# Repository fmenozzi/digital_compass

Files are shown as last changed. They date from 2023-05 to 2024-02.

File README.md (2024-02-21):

A digital compass that uses an LED ring to display the compass rose.

Upon startup, the compass enters magnetometer calibration mode, shown by the led chase sequence:

https://github.com/fmenozzi/digital_compass/assets/4451432/49a2e2fe-652e-430a-9320-a2c4e0b69866

During calibration, the compass should be moved around in all directions. Calibration ends after calibrated values do not change for five seconds.

Once the chase sequence ends, the compass rose will be displayed and the compass is now active, with the red LED pointing *very roughly* north:

https://github.com/fmenozzi/digital_compass/assets/4451432/9e37ce8d-d3a7-4e10-ac38-1c5cc8147863

Accuracy will suffer for a couple of reasons, such as being limited to only 24 possible directions and the magnetometer calibration being suboptimal. Regardless, this was a fun little proof-of-concept project for me, and my first non-trivial hardware project.

The microcontroller is a Seeeduino Xiao, and the magnetometer board uses the QMC5883L chip. The LED ring is an Adafruit Neopixel Ring 24, and a basic level shifter board does the conversions between the Xiao's needed 3.3V and 5V.

The software was programmed using Arduino. The circuit board was designed in KiCAD and manufactured by JLCPCB. The 3D-printed enclosure was designed in FreeCAD.

All software, schematics, and design files are licensed under the [MIT license](https://mit-license.org/).

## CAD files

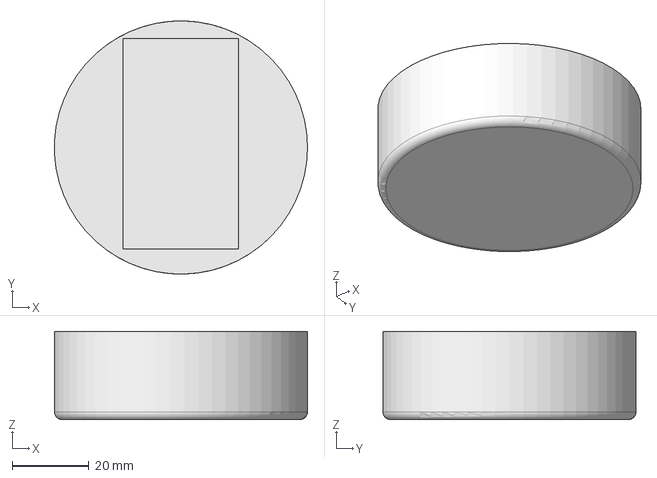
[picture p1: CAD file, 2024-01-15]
enclosure/bottom.FCStd
65.9 x 66.0 x 23.0 mm

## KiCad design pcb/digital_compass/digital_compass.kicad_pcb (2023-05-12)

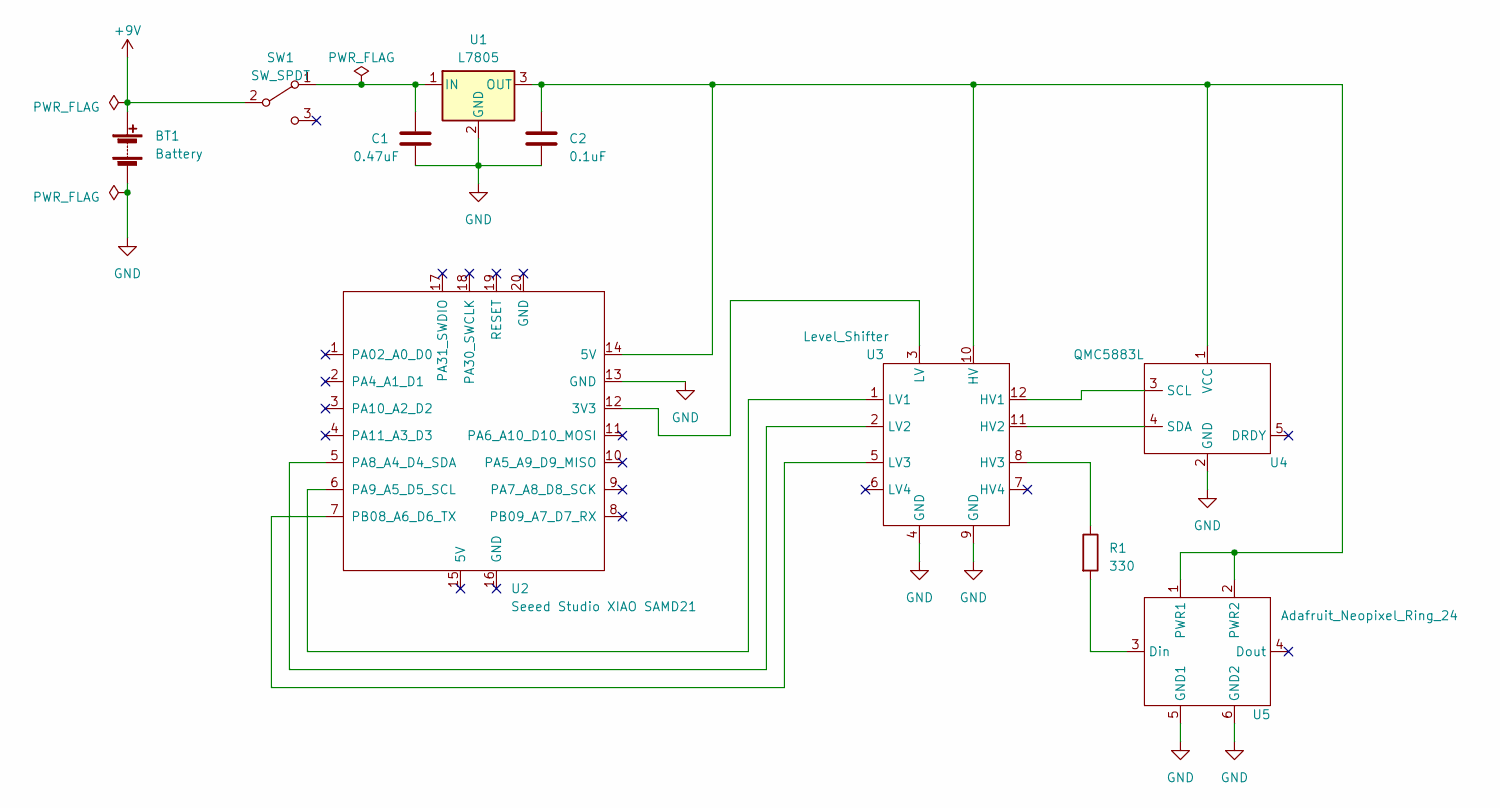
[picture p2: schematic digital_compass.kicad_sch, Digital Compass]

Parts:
BT1: Battery; BatteryHolder_Eagle_12BH611-GR
C1: 0.47uF; C_1206_3216Metric_Pad1.33x1.80mm_HandSolder
C2: 0.1uF; C_1206_3216Metric_Pad1.33x1.80mm_HandSolder
R1: 330; R_1206_3216Metric_Pad1.30x1.75mm_HandSolder
SW1: SW_SPDT; JS102011SCQN_SPDT_Switch
U1: L7805; TO-252-3_TabPin2
U2: Seeed Studio XIAO SAMD21; XIAO-SAMD21-RP2040-14P-2.54-21X17.8MM (Seeeduino XIAO)
U3: Level_Shifter
U4: QMC5883L
U5: Adafruit_Neopixel_Ring_24; Adafruit Neopixel Ring 24

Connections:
+9V: BT1.1 (+), SW1.2 (B)
GND: BT1.2 (-), C1.2, C2.2, U1.2 (GND), U2.13 (GND), U3.4 (GND), U3.9 (GND), U4.2 (GND), U5.5 (GND1), U5.6 (GND2)
unnamed: C1.1, SW1.1 (A), U1.1 (IN)
unnamed: C2.1, U1.3 (OUT), U2.14 (5V), U3.10 (HV), U4.1 (VCC), U5.1 (PWR1), U5.2 (PWR2)
unnamed: U2.12 (3V3), U3.3 (LV)
unnamed: U2.5 (PA8_A4_D4_SDA), U3.2 (LV2)
unnamed: U2.6 (PA9_A5_D5_SCL), U3.1 (LV1)
unnamed: U2.7 (PB08_A6_D6_TX), U3.5 (LV3)
unnamed: U3.12 (HV1), U4.3 (SCL)
unnamed: U3.11 (HV2), U4.4 (SDA)
unnamed: R1.1, U3.8 (HV3)
unnamed: R1.2, U5.3 (Din)

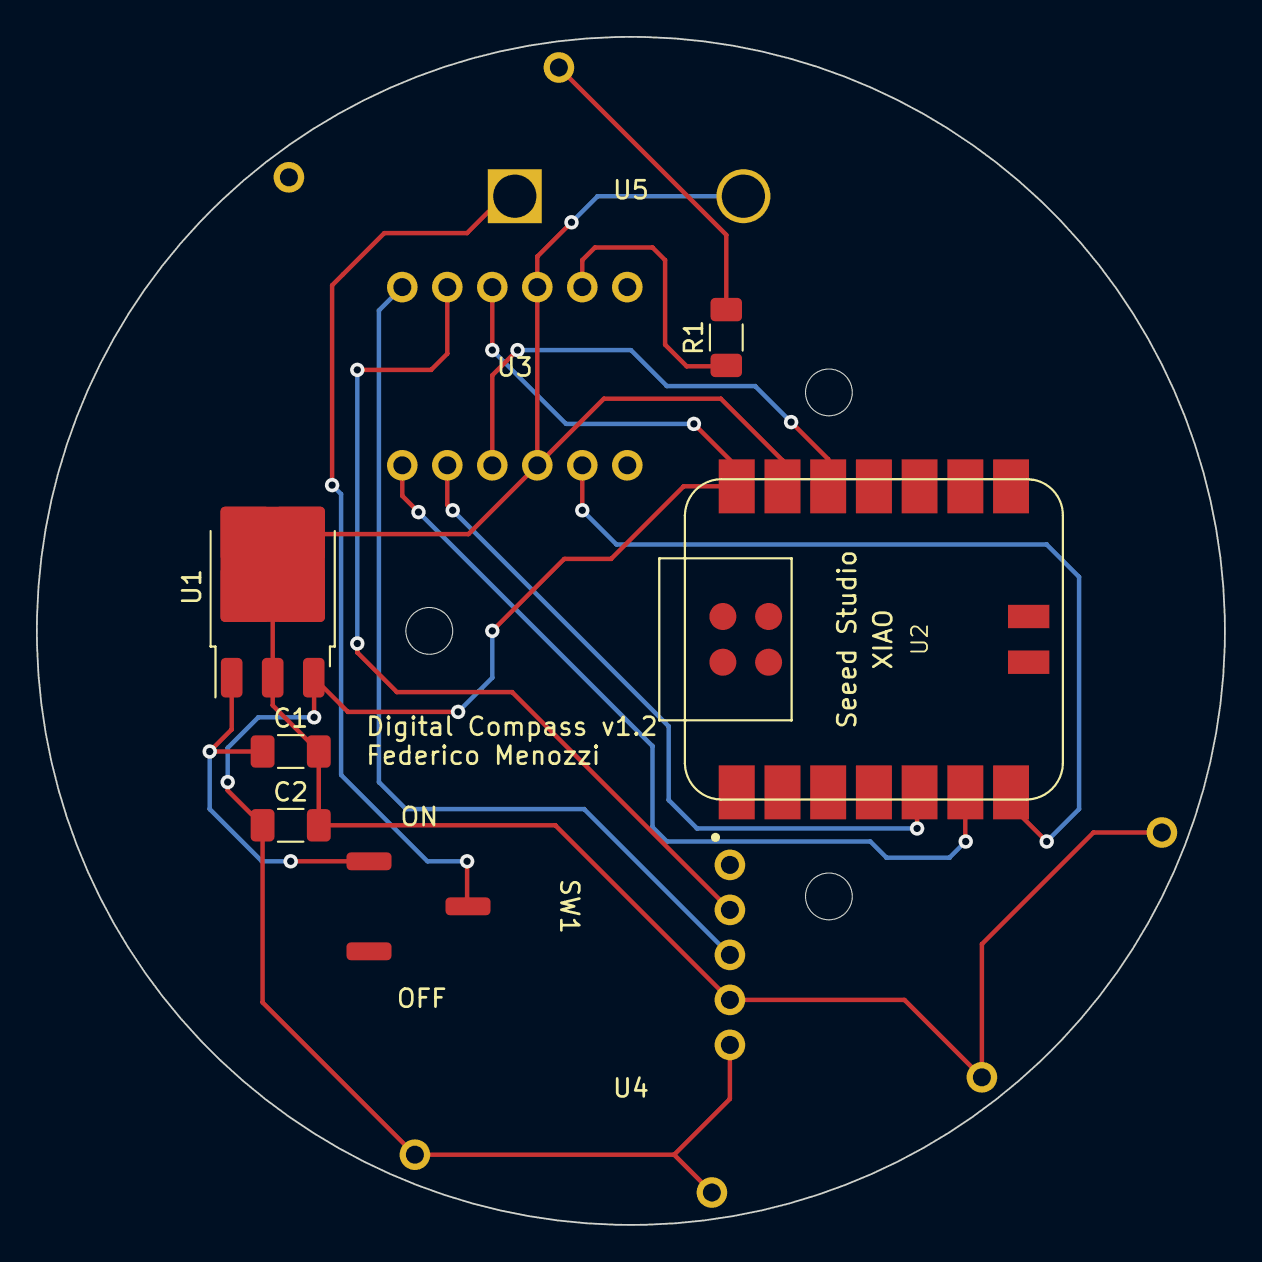
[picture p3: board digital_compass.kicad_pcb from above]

Board: 2 copper layers, 66.0 x 66.0 mm, 10 parts (1 on the bottom side), 12 nets.

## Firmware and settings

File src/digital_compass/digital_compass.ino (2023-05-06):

#include <FastLED.h>
#include <QMC5883LCompass.h>

const int NUM_LEDS = 24;
const int DATA_PIN = 6;
const int DELAY_MS = 50;

CRGB ring[NUM_LEDS];

QMC5883LCompass compass;

void setup() {
  FastLED.addLeds<NEOPIXEL, DATA_PIN>(ring, NUM_LEDS);
  FastLED.setBrightness(32);
  FastLED.clear();

  calibrate();
}

void calibrate() {
  int x0 = 0, x1 = 0, y0 = 0, y1 = 0, z0 = 0, z1 = 0;
  int i0 = 0, i1 = 1, i2 = 2, i3 = 3;
  int x, y, z;
  bool changed = false;
  int t = 0;
  int c = 0;

  compass.init();

  while (1) {
    // Nice ring chase sequence while we calibrate.
    FastLED.clear();
    ring[i0] = CRGB::White;
    ring[i1] = CRGB::White;
    ring[i2] = CRGB::White;
    ring[i3] = CRGB::Red;
    FastLED.show();
    i0 = (i0 + 1) % NUM_LEDS;
    i1 = (i1 + 1) % NUM_LEDS;
    i2 = (i2 + 1) % NUM_LEDS;
    i3 = (i3 + 1) % NUM_LEDS;
    delay(40);

    compass.read();
    x = compass.getX();
    y = compass.getY();
    z = compass.getZ();

    changed = false;
    if (x < x0) {
      x0 = x;
      changed = true;
    }
    if (x > x1) {
      x1 = x;
      changed = true;
    }
    if (y < y0) {
      y0 = y;
      changed = true;
    }
    if (y > y1) {
      y1 = y;
      changed = true;
    }
    if (z < z0) {
      z0 = z;
      changed = true;
    }
    if (z > z1) {
      z1 = z;
      changed = true;
    }

    if (changed) {
      c = millis();
    }

    t = millis();

    if (t - c > 5000) {
      FastLED.clear();
      break;
    }
  }

  compass.setCalibration(x0, x1, y0, y1, z0, z1);
}

void draw_compass(int north_led_idx) {
  int idx_n = north_led_idx;
  int idx_e = (idx_n + NUM_LEDS*1/4) % NUM_LEDS;
  int idx_s = (idx_n + NUM_LEDS*2/4) % NUM_LEDS;
  int idx_w = (idx_n + NUM_LEDS*3/4) % NUM_LEDS;

  ring[idx_n] = CRGB::Red;
  ring[idx_e] = CRGB::White;
  ring[idx_s] = CRGB::White;
  ring[idx_w] = CRGB::White;

  FastLED.show();

  ring[idx_n] = CRGB::Black;
  ring[idx_e] = CRGB::Black;
  ring[idx_s] = CRGB::Black;
  ring[idx_w] = CRGB::Black;
}

// Determine the index of the Neopixel ring that corresponds to north, given
// the magnetometer heading in degrees. The top LED (that is, the LED pointing
// in the X-direction of the magnetometer) is index 0.
//
// Note that we want each arc centered on the LED, and not the LED's edge (e.g.
// for a Neopixel Ring 24, the arc angle will be 15 degrees, but since it's
// centered on the LED, the top LED will shine when the heading is between 352.5
// and 7.5 degrees).
//
// TODO: See if there's a closed form representation for this that doesn't
//       require this loop.
int convert_heading_to_north_led_index(float heading_deg) {
  const float ARC_ANGLE = 360.0 / NUM_LEDS;
  const float HALF_ARC_ANGLE = ARC_ANGLE / 2.0;
  for (int i = 0; i < NUM_LEDS; i++) {
    if (heading_deg < i*ARC_ANGLE + HALF_ARC_ANGLE) {
      return (NUM_LEDS - i) % NUM_LEDS;
    }
  }
  return NUM_LEDS - 1; // For the last half-arc
}

void loop() {
  compass.read();
  float heading = compass.getAzimuth();

  int north_led_idx = convert_heading_to_north_led_index(heading);
  draw_compass(north_led_idx);

  delay(DELAY_MS);
}

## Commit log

2022-12-10 Add preliminary code implementation.
    This code provides the bare-minimum functionality of a digital compass;
    that is, it measures the heading from the qmc5883l magnetometer and
    lights the appropriate leds on a 24-piece neopixel ring (i.e. in the
    cardinal directions).
    Future additions might include a debug mode for displaying magnetometer
    readings via serial, adding a calibration mode instead of hardcoding a
    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
2022-12-10 Create empty kicad project.
    [digital_compass.kicad_pcb, digital_compass.kicad_sch]
2022-12-11 Add initial footprint for neopixel ring 24.
    Not sure yet whether the hollow ring aspect was captured properly here.
2022-12-11 Add symbol for QMC5883L magnetometer.
2022-12-11 Add footprint for QMC588L.
2023-04-22 Finish basic digital compass schematic.
    * Based on updated xiao-based design
    * Also opened in KiCad 7
    [digital_compass.kicad_pcb, digital_compass.kicad_sch]
2023-04-23 Add/update footprints and run fp assignment.
    The footprints for the level shifter and magnetometer boards were
    created manually, but the xiao symbol/footprint were taken from
    https://github.com/Seeed-Studio/OPL_Kicad_Library.
    Note that the xiao symbol was lightly tweaked to pass ERC, as the pins
    were not properly labeled as power inputs/outputs, bidirectional, etc.
    [digital_compass.kicad_sch]
2023-04-23 Add SPDT slide power switch.
    For now we just choose an ok-looking smd footprint but we may need to
    make a custom one depending on what we actually find with suppliers.
    [digital_compass.kicad_sch]
2023-04-23 Use custom footprint for SPDT switch.
    Based on https://www.ckswitches.com/media/1422/js.pdf. Also move the
    switch to the regulated side of the L7805, as this switch can only
    handle up to 6V.
    [digital_compass.kicad_sch]
2023-04-23 Create initial layout (no traces).
    The magnetometer and level shifter boards may be changed to use
    throughhole footprints instead of smd, but the size/layout shouldn't
    need to change in that case.
    [digital_compass.kicad_pcb]
2023-04-23 Update mag/shifter footprints to use THT pads.
2023-04-23 Add initial routing for pcb.
    This currently passes the existing design rule checks, though I may need
    to go back and tweak some placements once I add the JLCPCB-specific
    design rules as well.
    [digital_compass.kicad_pcb]
2023-04-24 Update schematic date and add helper silkscreen.
    Silkscreen includes ON/OFF for the power switch and project
    name/version/author lines.
    [digital_compass.kicad_pcb, digital_compass.kicad_sch]
2023-04-24 Set up design rules/constraints for jlcpcb.
    Taken from https://jlcpcb.com/capabilities/pcb-capabilities.
    Also correct two existing DRC violations.
    [digital_compass.kicad_pcb]
2023-04-24 Generate gerbers/drill files for jlcpcb.
    [digital_compass-B_Cu.gbl, digital_compass-B_Mask.gbs, digital_compass-B_Paste.gbp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]
2023-05-06 Calibrate automatically on startup.
2023-05-06 Fix magnetometer and update schematic/pcb/gerbers.
    Turns out the original v1 magnetometer footprint had the pins in reverse
    order, so update the footprint/schematic/pcb/gerbers for round two at
    jlcpcb.
    [digital_compass-B_Cu.gbl, digital_compass-B_Mask.gbs, digital_compass-B_Paste.gbp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]
2023-05-12 Fix power switch and update schematic/pcb/gerbers.
    Turns out the L7805 consumes power when connected to an input power
    source even if the output is disconnected. We therefore move the power
    switch to the input side of the regulator to prevent power consumption
    when the compass is turned off.
    [digital_compass-B_Cu.gbl, digital_compass-B_Mask.gbs, digital_compass-B_Paste.gbp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]
2023-05-12 First pass at an enclosure.
    For now this is a single simple bottom piece, a cylinder with a pocket
    to fit the battery holder. We intentionally did not incorporate any
    additive printer tolerance into measurements in order to see whether
    it's possible to get a snug fit without any additional parts/fasteners.
    [bottom.FCStd]
2024-01-15 Adjust enclosure tolerance for better fit.
    [bottom.FCStd]

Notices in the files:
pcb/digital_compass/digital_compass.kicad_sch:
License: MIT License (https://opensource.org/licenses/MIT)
